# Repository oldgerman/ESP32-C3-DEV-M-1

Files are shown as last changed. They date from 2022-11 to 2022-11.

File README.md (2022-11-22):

## ESP32-C3-DevKitM-1

> 基于ESP32-C3的开发板，[ESP32-C3-DEVKITM-1](https://docs.espressif.com/projects/esp-idf/zh_CN/latest/esp32c3/hw-reference/esp32c3/user-guide-devkitm-1.html)的重制版，保持十分考究的布局，提供AD原始工程、Gerber、BOM

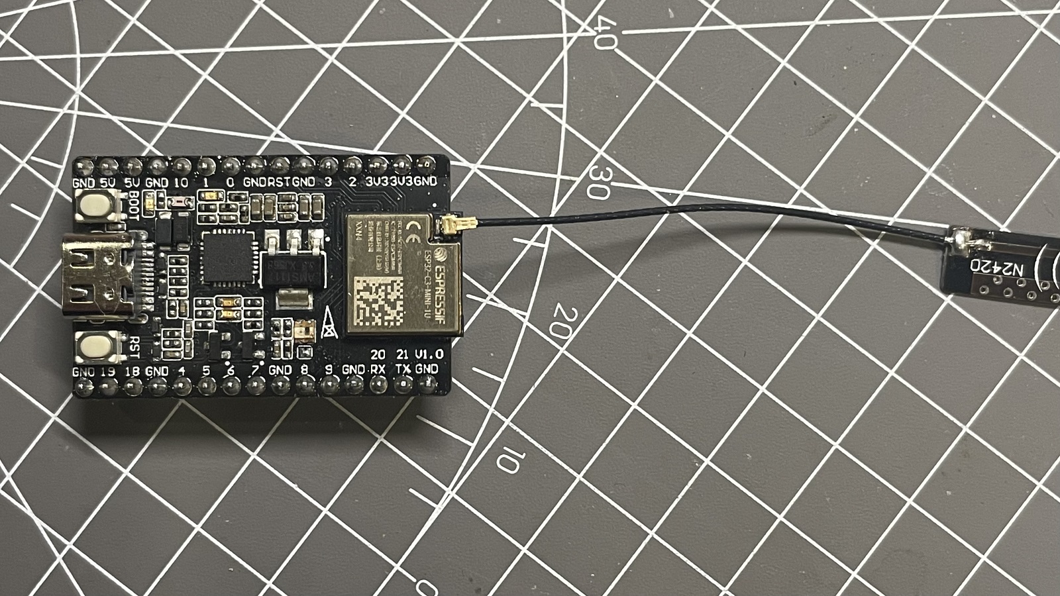
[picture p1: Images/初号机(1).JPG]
初号机(1)


[Github仓库链接](https://github.com/oldgerman/ESP32-C3-DEV-M-1)

## PCB

| 使用ESP32-C3 MINI-1模组 | 使用ESP32-C3 MINI-1U模组 |
| --- | --- |
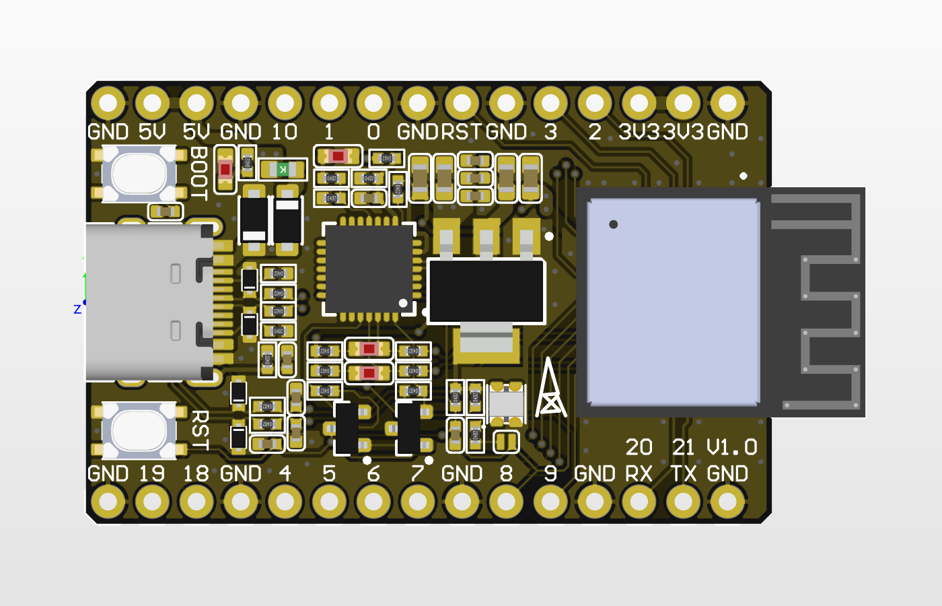
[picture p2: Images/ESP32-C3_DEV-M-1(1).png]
ESP32-C3_DEV-M-1(1)
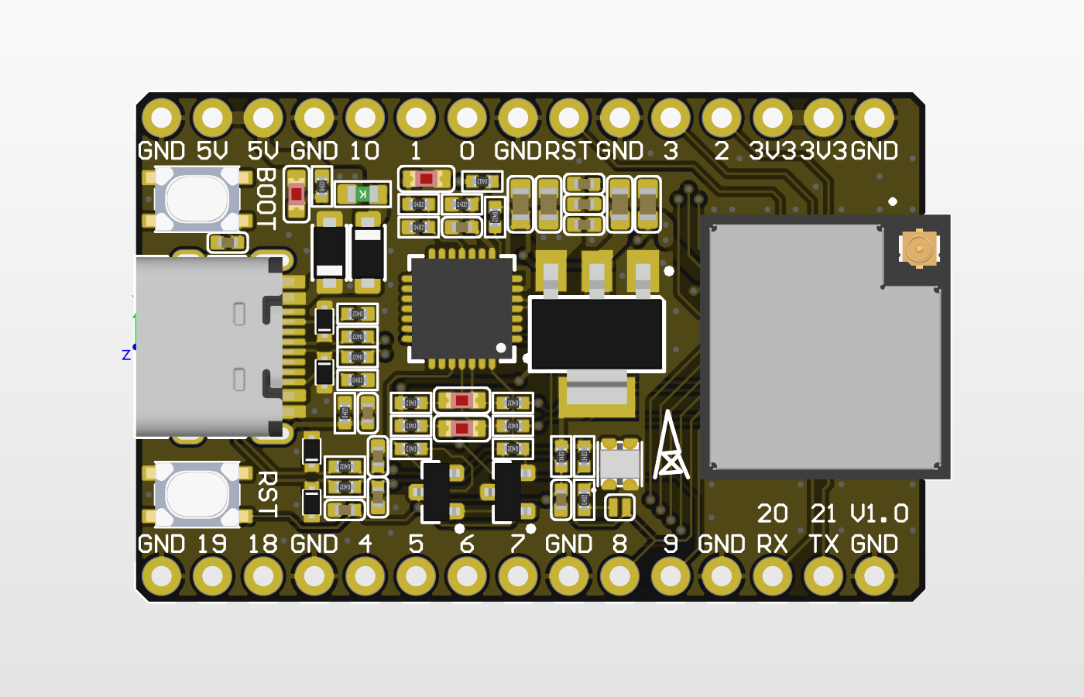
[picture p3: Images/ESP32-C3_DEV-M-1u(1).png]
ESP32-C3_DEV-M-1u(1)
|  |  |
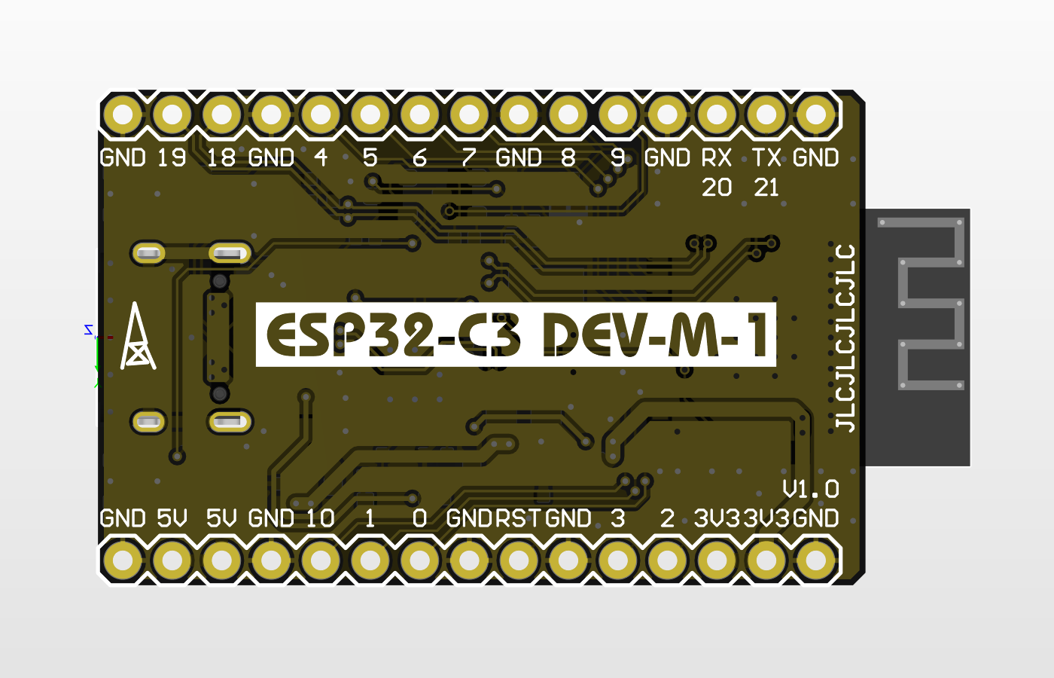
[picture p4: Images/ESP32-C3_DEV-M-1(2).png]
ESP32-C3_DEV-M-1(2)
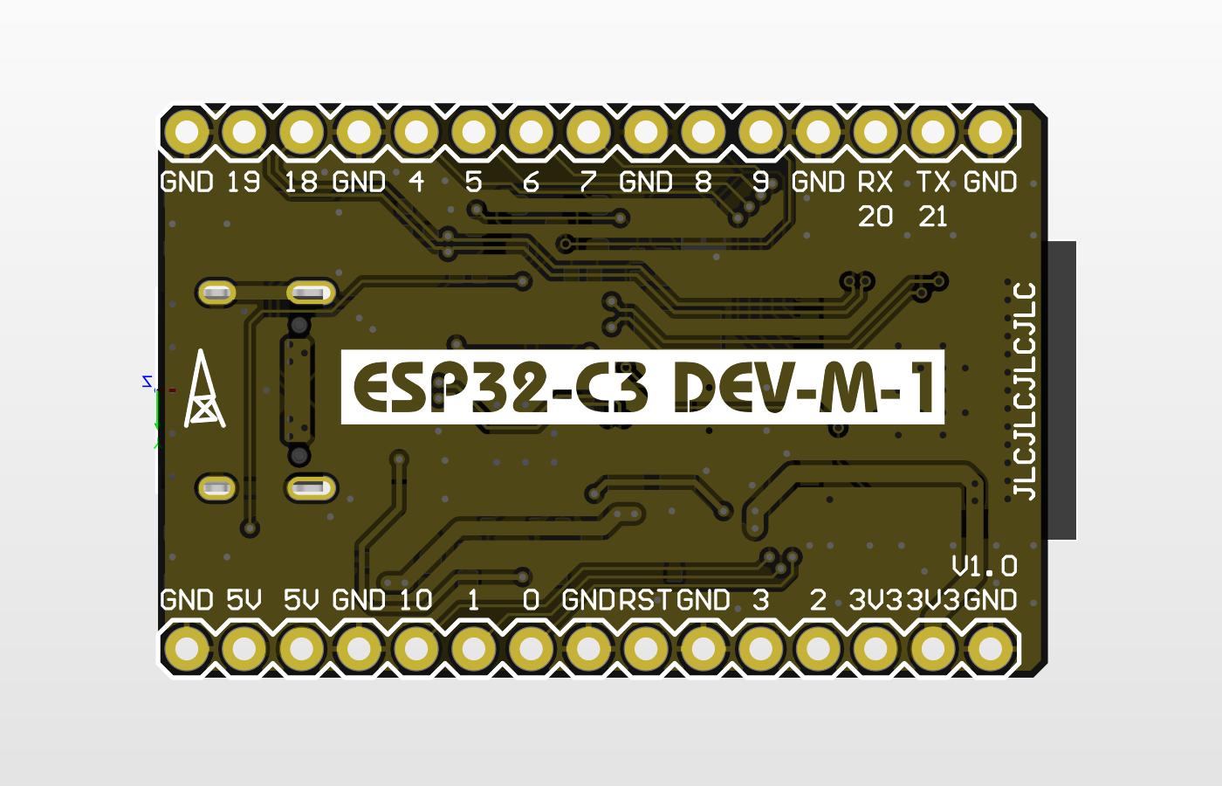
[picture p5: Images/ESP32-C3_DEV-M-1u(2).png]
ESP32-C3_DEV-M-1u(2)
|  |  |
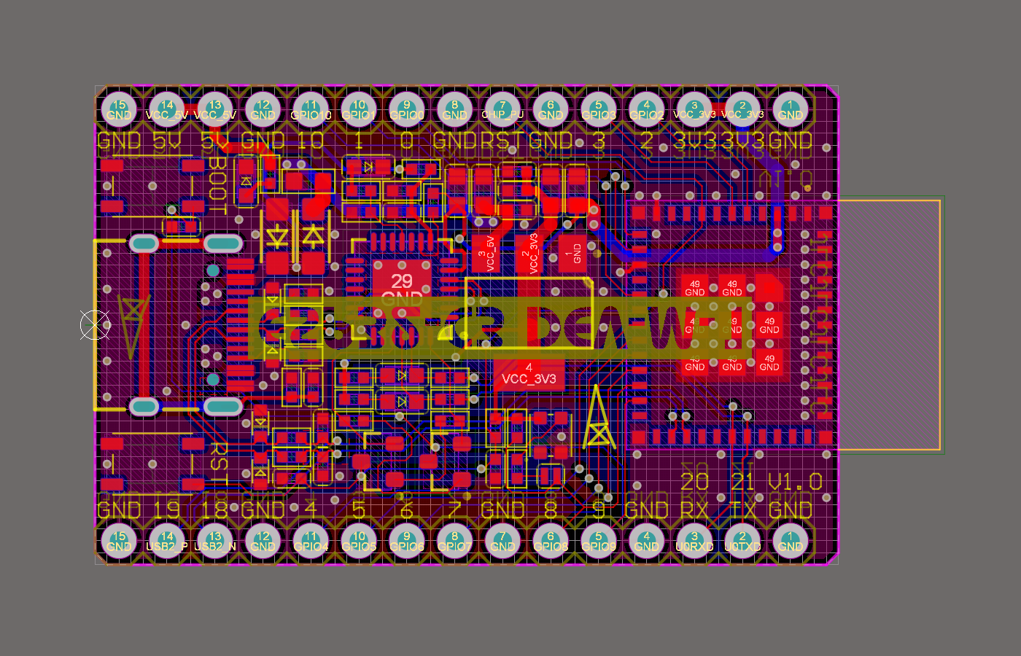
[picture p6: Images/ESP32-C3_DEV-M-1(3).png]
ESP32-C3_DEV-M-1(3)
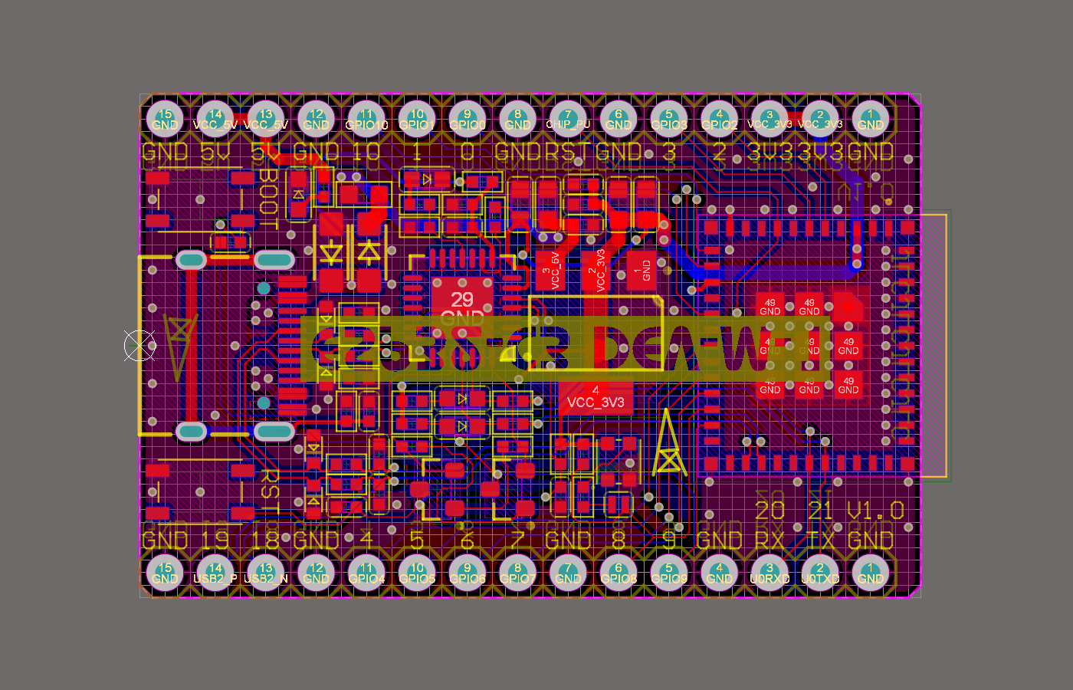
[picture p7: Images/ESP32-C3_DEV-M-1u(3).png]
ESP32-C3_DEV-M-1u(3)
|  |  |

## 工艺

- 板厚：1.0~1.6mm 均可
- 层数：2层
- 过孔：0.3/0.5mm
- 最小线宽线隙：5mil

## Type-C正反插

- 正插：使用CP2102的串口
- 反插：使用ESP32-C3FN4或ESP32-C3FH4片内集成的USB串口，可以不焊接CP2102相关的电路使用ESP32-C3自带的USB串口桥烧录或者调试

## 亮机测试

模组焊接很难，对锡膏均匀度要求很高，不开钢网很难搞

Example文件夹内有最基本的wifi、GPIO、串口、RGB灯测试

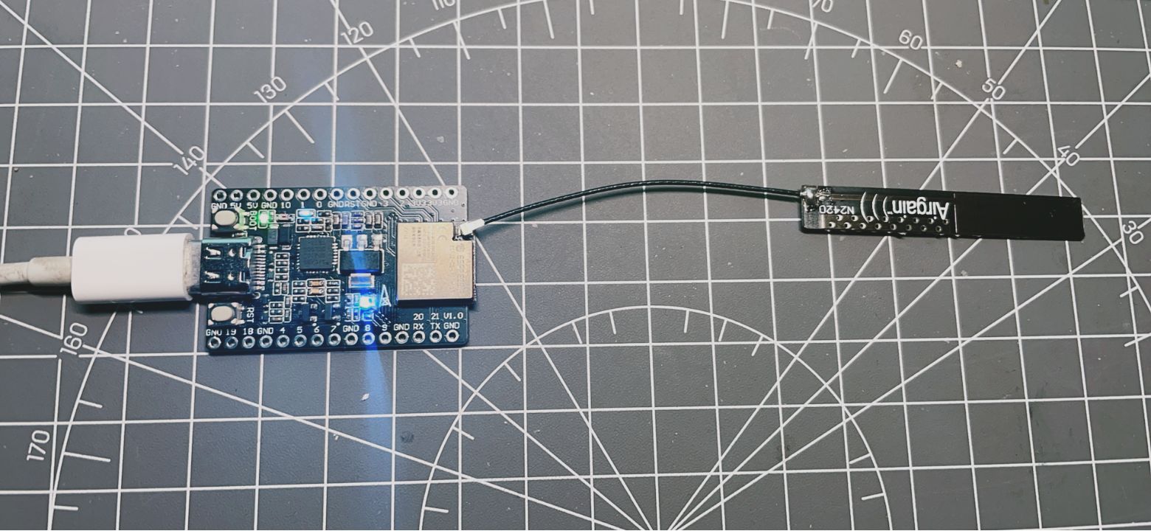
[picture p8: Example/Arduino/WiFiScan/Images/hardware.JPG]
hardware


## 烧录程序

乐鑫工具：[Flash Download Tools](https://www.espressif.com/en/support/download/other-tools)

Arduino环境：简单些，一键选择esp32-c3开发板，一键就行

ESP-IDF：待补充

## 按键boot和reset组合，尝试进入下载模式，但不打印 “waiting for download”，仍然一直打印invalid header: 0xffffffff？

使用全新的模组，首次焊接好通电，不论是esp32-c3自身串口，还是cp2102的串口，会一直打印invalid header: 0xffffffff，然后自己复位，如此反复，如果GPIO8是高电平，按键boot和reset组合进入下载模式却不打印 “waiting for download”，那么是正常现象，因为出厂是不带BOOT的，可以使用flash_download_tool连接开发板进入下载模式，只需要连接一次，烧录bootloader.bin在0x0地址，然后就可以按下boot键不放，按下松开一次reset键，进入下载模式就会打印 “waiting for download”，或者随便烧录一个arduino esp32-c3例程进去，也可以解决

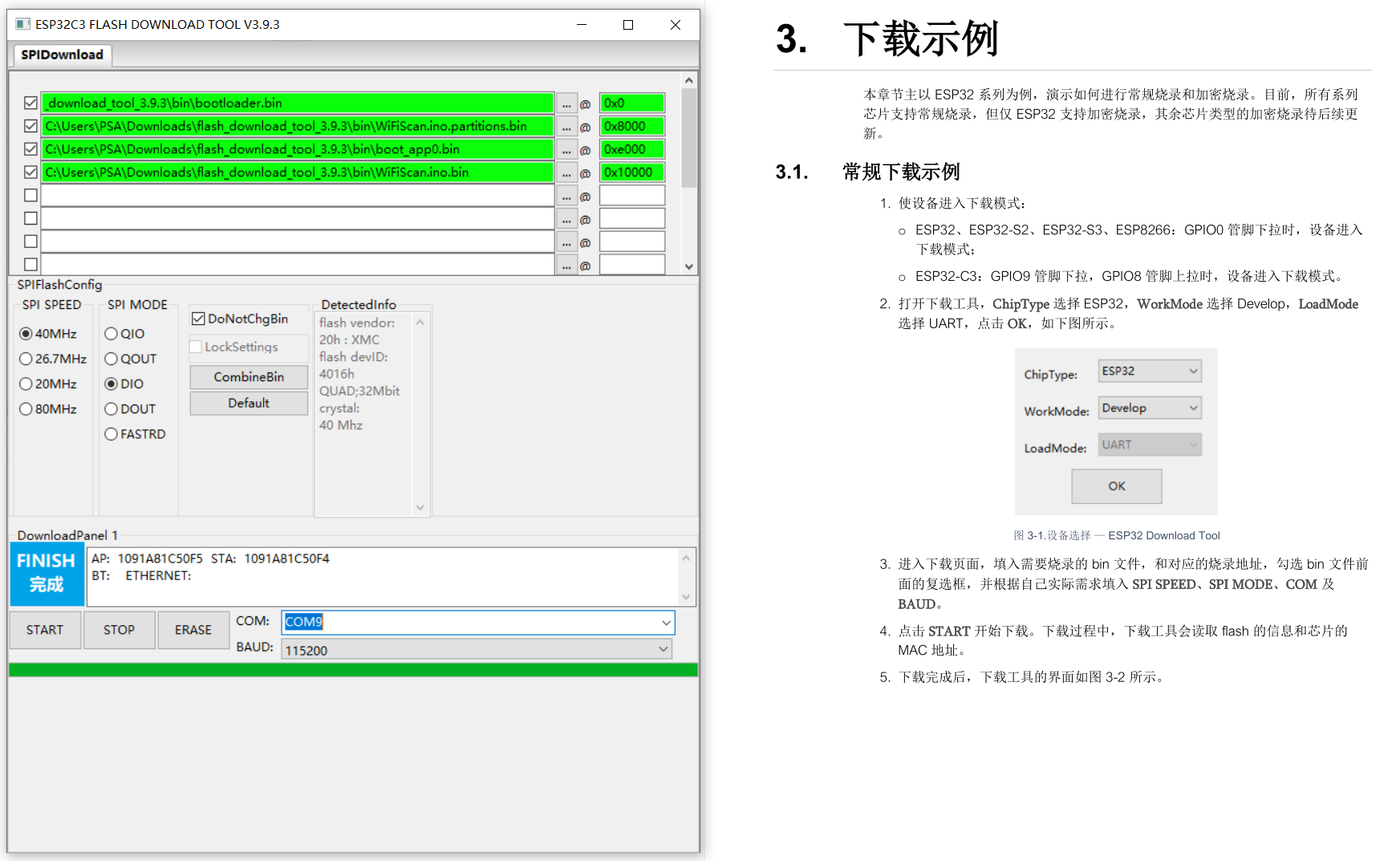
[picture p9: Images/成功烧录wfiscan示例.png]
成功烧录wfiscan示例


```
ESP-ROM:esp32c3-api1-20210207
Build:Feb  7 2021
rst:0x15 (USB_UART_CHIP_RESET),boot:0x4 (DOWNLOAD(USB/UART0/1))
Saved PC:0x400462e2
waiting for download   <----按键boot和reset组合，尝试进入下载模式OK，esp32-3本身片内的串口桥或者cp2102都可以
```

## 碎碎念

最近的准备用STM32测试[esp-hosted](https://github.com/espressif/esp-hosted)，ESP32-C3拥有[ESP-Hosted-FG]() SPI模式最高的吞吐量(TX/RX 17Mbps)，[ESP32-C3 MINI-1U]()模组又是这几款ESP32提供的模组中尺寸最小的，遂选型之，由于直接使用模组，那么就不用设计模组内的电路部分了，直接找乐鑫官网[ESP32-C3-DEVKITM-1](https://docs.espressif.com/projects/esp-idf/zh_CN/latest/esp32c3/hw-reference/esp32c3/user-guide-devkitm-1.html)开发板（都2202年了还是Micro-USB接口？）提供的原理图和PDF格式的PCB布局做参考，本以为[ESP32-C3-DEVKITM-1](https://docs.espressif.com/projects/esp-idf/zh_CN/latest/esp32c3/hw-reference/esp32c3/user-guide-devkitm-1.html)这块两层板挺好搞定，然而细看背面布局发现画板子的工程师追求连续的GND（UART总线或者USB差分对与其他信号线之间必有GND），给改Type-C增加了不少麻烦

## 参考资料

[ESP32-C3-DevKitM-1：快速入门](https://docs.espressif.com/projects/esp-idf/zh_CN/latest/esp32c3/hw-reference/esp32c3/user-guide-devkitm-1.html)

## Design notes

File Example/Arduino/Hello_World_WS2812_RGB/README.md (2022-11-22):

## 测试板子上的RGB灯

- WS2812按照色轮变化颜色
- 串口打印 hello World

<video src="Images/demo.MP4"></video>

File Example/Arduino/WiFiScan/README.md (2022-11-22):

## Wifi信号强度测试

- 测试：天线是否抽风

hardware

### Boot信息

```
ESP-ROM:esp32c3-api1-20210207
Build:Feb  7 2021
rst:0x1 (POWERON),boot:0xc (SPI_FAST_FLASH_BOOT)
SPIWP:0xee
mode:DIO, clock div:1
load:0x3fcd6100,len:0x420
load:0x403ce000,len:0x90c
load:0x403d0000,len:0x236c
SHA-256 comparison failed:
Calculated: ccb0d00bac7e84e1d90a12e4f75f4ab6c5f7e71bb209afd5819c4c9557a6db71
Expected: c9cf160580940ec7801c73b16423824e72ad12055c732e83ce66332240af42a7
Attempting to boot anyway...
entry 0x403ce000
Setup done
```

### 未安装天线前

```
scan start
scan done
2 networks found
1: PDCN (-59)*
2: PDCN (-91)*

scan start
scan done
2 networks found
1: PDCN (-67)*
2: PDCN (-90)*

scan start
scan done
2 networks found
1: PDCN (-58)*
2: PDCN (-87)*

scan start
scan done
1 networks found
1: PDCN (-63)*

scan start
scan done
2 networks found
1: PDCN (-58)*
2: PDCN (-92)*

```

### 安装4dBi 天线

####   距离路由器天线60cm

```
scan start
scan done
5 networks found
1: PDCN (-7)*
2: PDCN (-38)*
3: ROOM (-72)*
4: @PHICOMM_54 (-75)*
5: suibianwo (-80)*

scan start
scan done
4 networks found
1: PDCN (-12)*
2: PDCN (-38)*
3: @PHICOMM_54 (-73)*
4: ROOM (-73)*
```

#### 距离路由器天线5cm

```

scan start
scan done
7 networks found
1: PDCN (-26)*
2: PDCN (-55)*
3: D5-4-2 (-75)*
4: TP-LINK_C341 (-86)*
5: zhang (-87)*
6: Wireless Router (-89) 
7: suibianwo (-89)*

scan start
scan done
8 networks found
1: PDCN (-30)*
2: PDCN (-56)*
3: D5-4-2 (-87)*
4: @PHICOMM_54 (-88)*
5: D-6-1 (-88)*
6: suibianwo (-89)*
7: lyf (-89)*
8: 360WiFi-2FF6B6 (-90)*

```

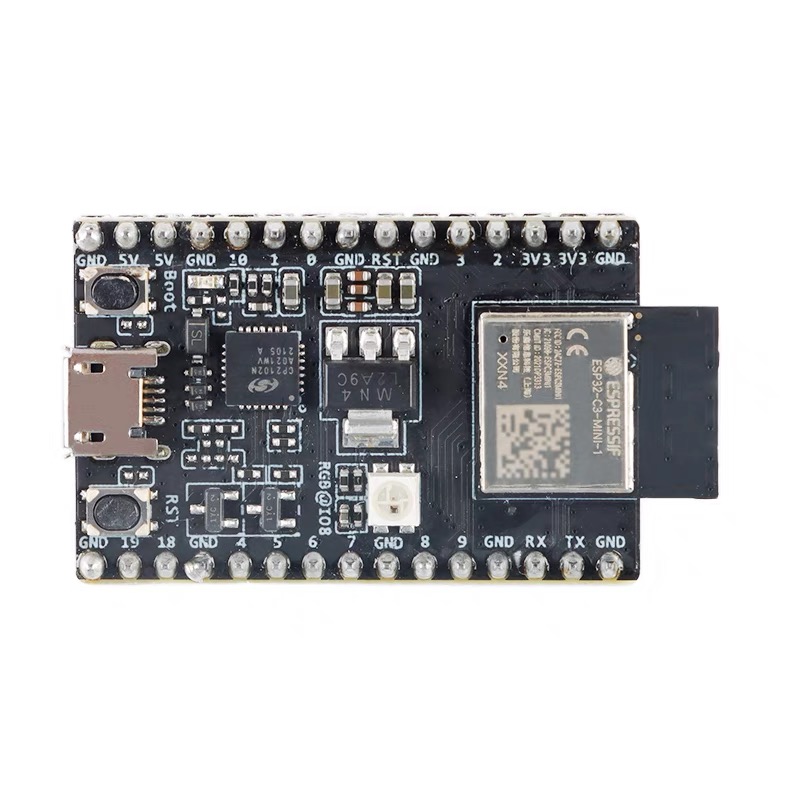
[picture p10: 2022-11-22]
Reference/ESP32-C3-DEVKITM-1/Images/ESP32-C3-DEVKITM-1_Brd(2).JPG

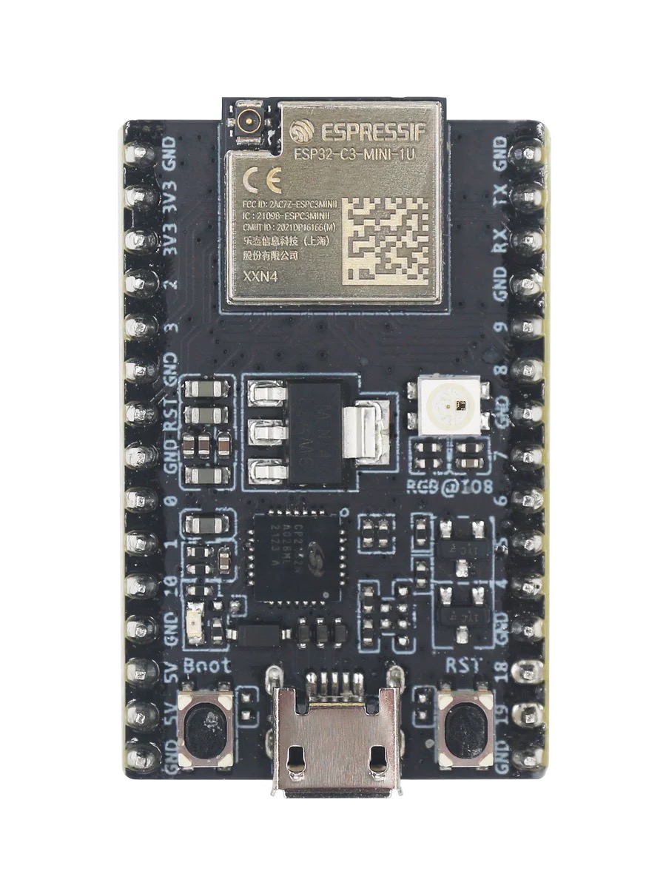
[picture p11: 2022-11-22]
Reference/ESP32-C3-DEVKITM-1/Images/ESP32-C3-DEVKITM-1_Brd(1).JPG

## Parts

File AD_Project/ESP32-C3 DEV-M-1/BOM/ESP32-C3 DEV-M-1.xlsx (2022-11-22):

Comment | Designator | Footprint
4.7nF | C1 | C0402
10uF/10V(10%) | C2, C7, C10, C11 | C0603
1uF/16V(10%) | C3, C4, C14 | C0402
22pF/50V(5%) | C5, C6 | C0402
0.1uF/50V(10%) | C8, C9, C12, C13 | C0402
DSK16 | D1 | SOD123F
SMF5.0A | D2 | SOD123F
ESD5B5.05T1G | D3, D4, D5, D6 | SOD-523
6V/0.5A/1A | F1 | FUSE0603_0.5MM
LED | LED1, LED2, LED3, LED4 | LED0603_RED
ODG_LOGO | ODG1, ODG2 | ODG_LOGO
CONN_X15 | P1, P2 | 2.54MM_MALE_X15
S8050 | Q1, Q2 | INFINEON SOT-23-3
5.1K(1%) | R1, R2, R12, R21, R22 | R0402
1M | R3 | R0402
47K(1%) | R16 | R0402
22R(1%) | R5, R6, R7, R8, R10, R11 | R0402
10K(1%) | R4, R9 | R0402
10K(1%)(NC) | R13 | R0402
22K(1%) | R14 | R0402
1K(1%) | R15 | R0402
0R(1%) | R17 | R0402
3.3K(1%) | R18, R19, R20 | R0402
SJ_2P | SJ1 | SJ_2P_MINI
Button-4P | SW1, SW2 | SWITCH_3X4X2.5_4PIN_SMD
ESP32-C3-MINI-1U-N4 (A) | U1 | XCVR_ESP32-C3-MINI-1U-N4
AMS1117-3.3 | U2 | TI SOT-223 DCY
CP2102-GMR | U3 | QFN-28_EP
WS2812 | U4 | WS2812_2020
Type-C | USB1 | Type-C-TOP

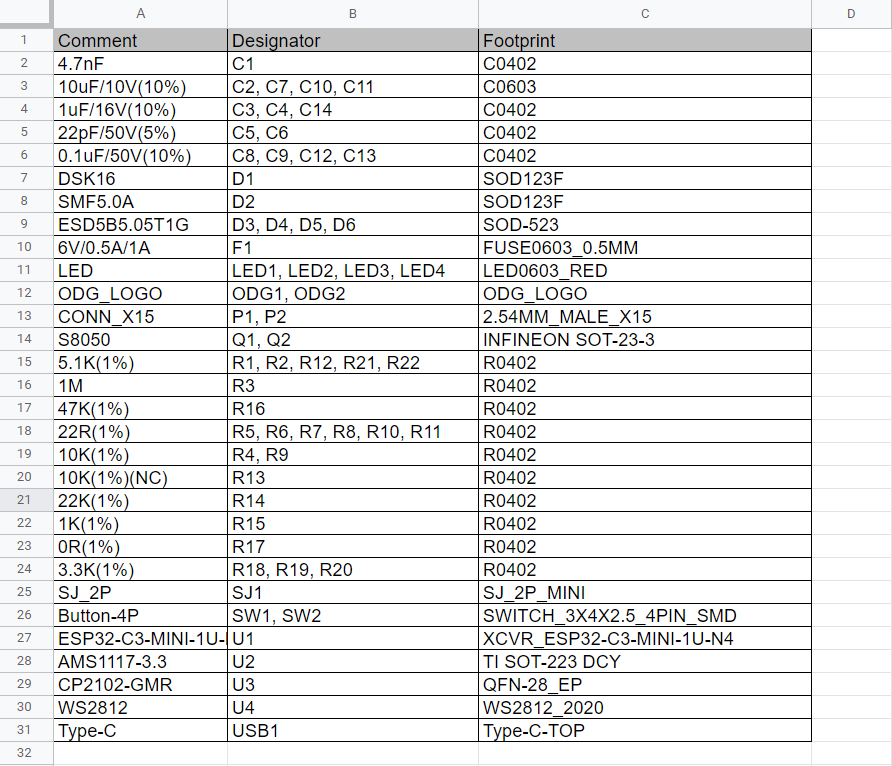
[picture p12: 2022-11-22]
AD_Project/ESP32-C3 DEV-M-1/BOM/BOM.png

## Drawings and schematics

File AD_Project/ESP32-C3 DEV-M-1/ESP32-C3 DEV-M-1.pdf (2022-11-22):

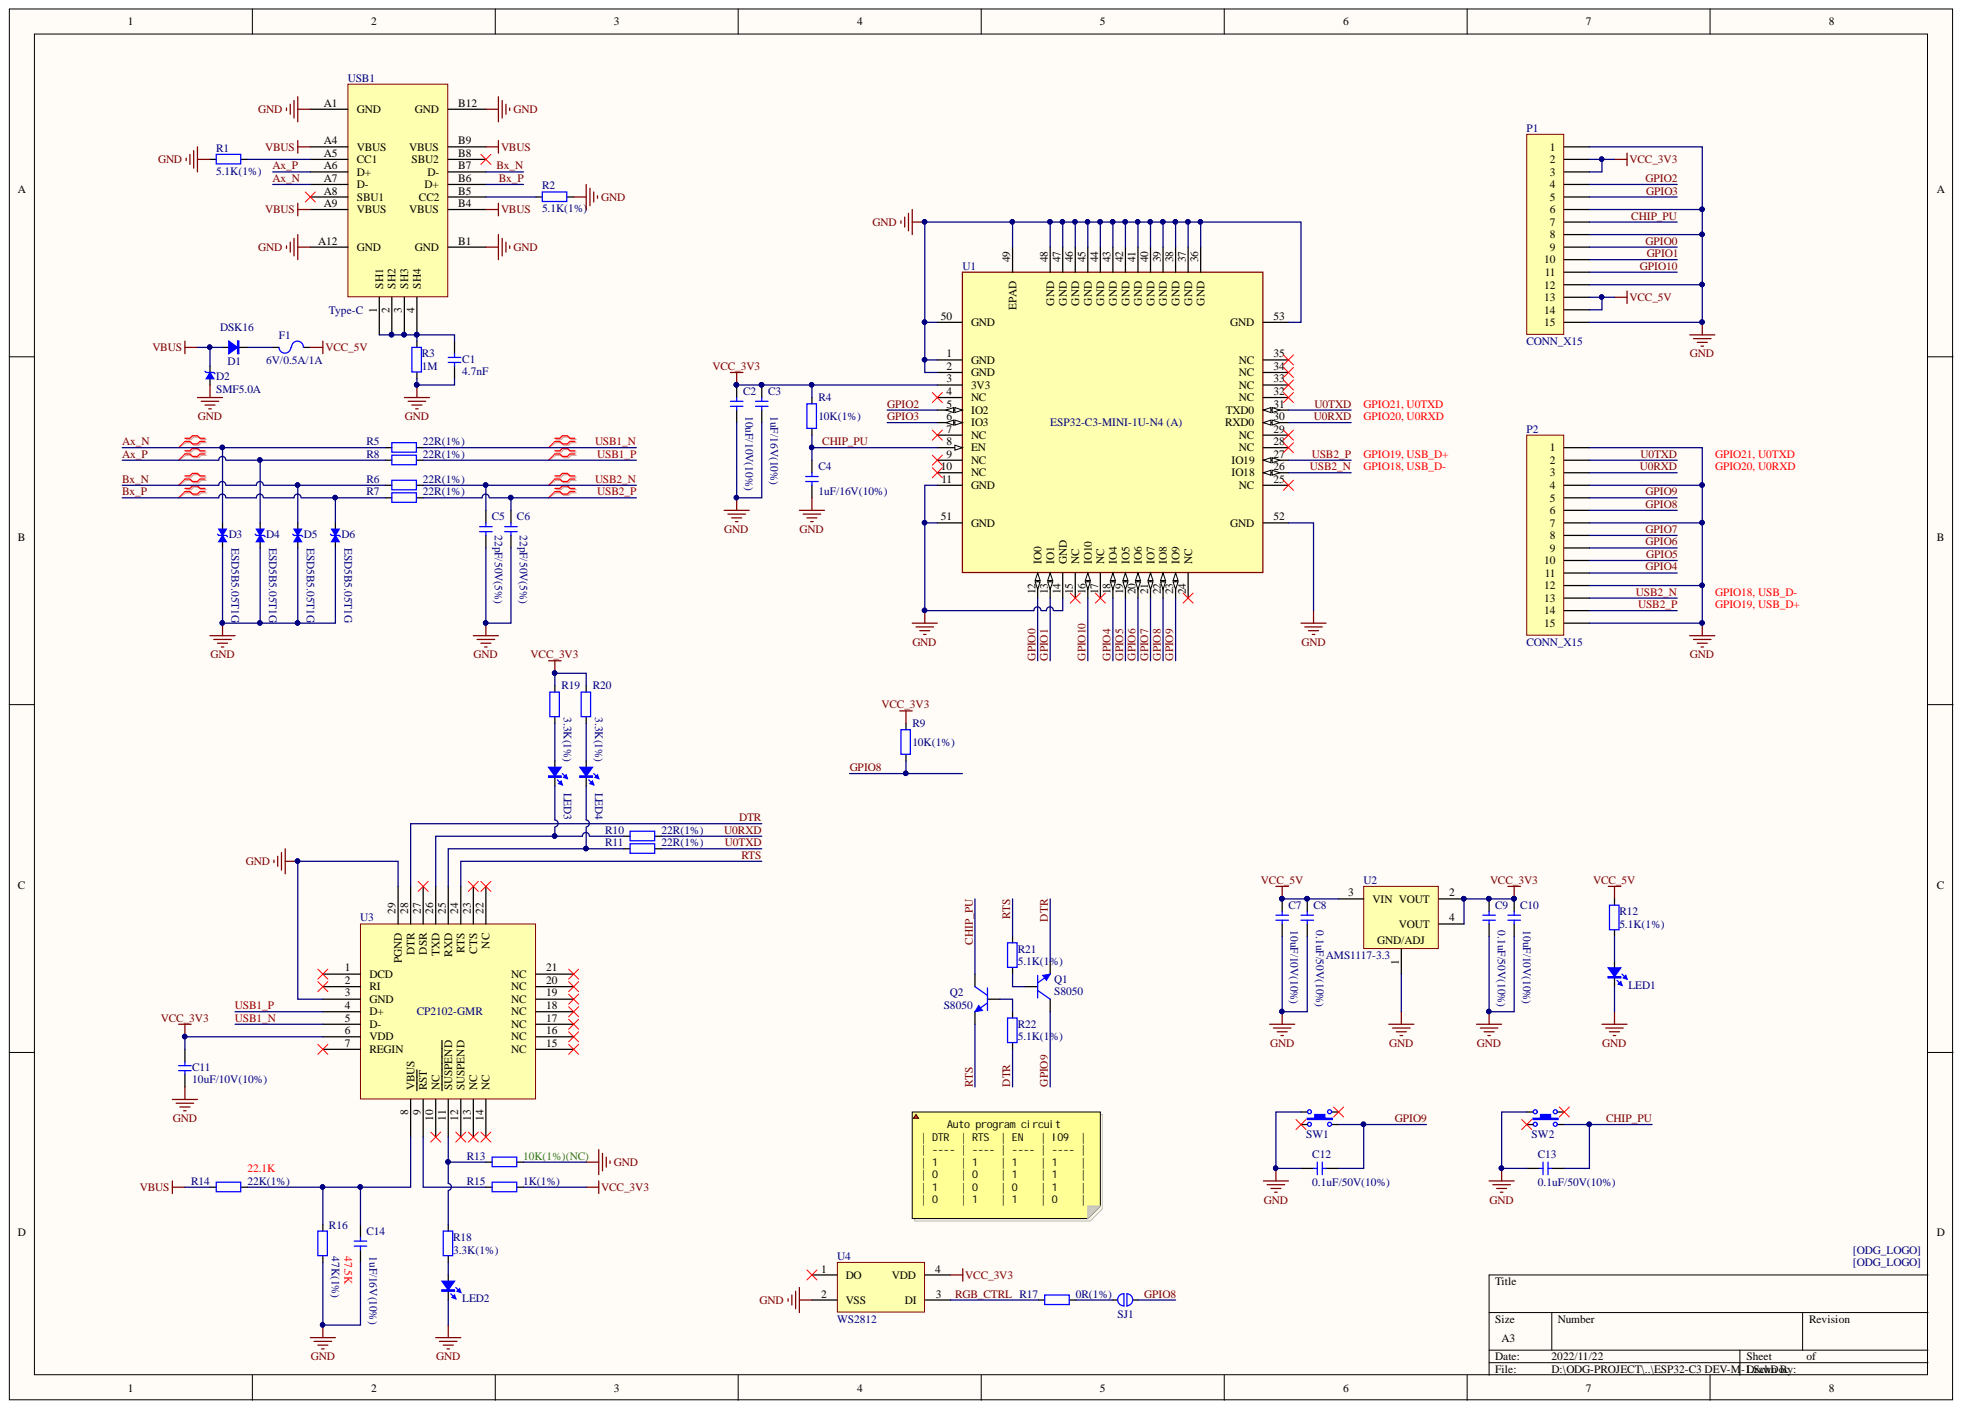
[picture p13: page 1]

GND 36 GND 37 GND 38 GND 39 GND 40 GND 41 GND 42 GND 43 GND 44 GND 45 GND 46 GND 47 GND 48

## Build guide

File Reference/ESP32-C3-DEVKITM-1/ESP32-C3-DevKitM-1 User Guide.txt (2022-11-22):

https://docs.espressif.com/projects/esp-idf/zh_CN/latest/esp32c3/hw-reference/esp32c3/user-guide-devkitm-1.html
https://docs.espressif.com/projects/esp-idf/zh_CN/latest/esp32c3/hw-reference/esp32c3/user-guide-devkitm-1.html
https://docs.espressif.com/projects/esp-idf/zh_CN/latest/esp32c3/hw-reference/esp32c3/user-guide-devkitm-1.html

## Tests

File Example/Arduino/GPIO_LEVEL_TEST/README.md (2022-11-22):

## 简单粗暴的GPIO电平翻转测试

- 测试对象：GPIO0-->10，GPIO18-->21，即开发板15个引出到2.54杜邦接口的GPIO
- 例程：5Hz方波，奇数与偶数GPIO电平互为相反，因为模组的GPIO是奇偶奇偶排列的，所以可以检查焊接问题，虚焊&连锡

## demo

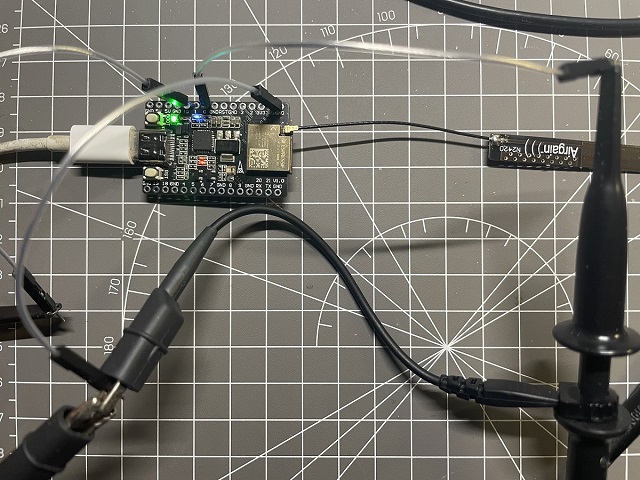
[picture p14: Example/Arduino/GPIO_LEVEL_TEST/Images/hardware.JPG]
hardware
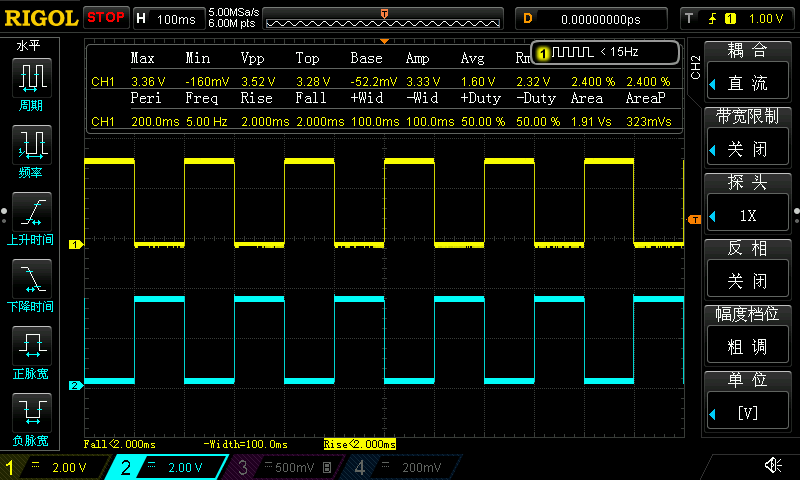
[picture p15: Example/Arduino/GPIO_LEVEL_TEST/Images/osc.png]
osc
|  |  |
| --- | --- |

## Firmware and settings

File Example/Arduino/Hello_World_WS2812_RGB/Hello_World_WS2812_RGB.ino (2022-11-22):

/*
  Blink

  Turns an LED on for one second, then off for one second, repeatedly.

  Most Arduinos have an on-board LED you can control. On the UNO, MEGA and ZERO
  it is attached to digital pin 13, on MKR1000 on pin 6. LED_BUILTIN is set to
  the correct LED pin independent of which board is used.
  If you want to know what pin the on-board LED is connected to on your Arduino
  model, check the Technical Specs of your board at:
  https://www.arduino.cc/en/Main/Products

  modified 8 May 2014
  by Scott Fitzgerald
  modified 2 Sep 2016
  by Arturo Guadalupi
  modified 8 Sep 2016
  by Colby Newman

  This example code is in the public domain.

  http://www.arduino.cc/en/Tutorial/Blink
*/


#include <Adafruit_NeoPixel.h>


// Which pin on the Arduino is connected to the NeoPixels?
// On a Trinket or Gemma we suggest changing this to 1:
#define LED_PIN     8 //ESP32-C3 GPIO8

// How many internal neopixels do we have? some boards have more than one!
#define NUMPIXELS        1

// NeoPixel brightness, 0 (min) to 255 (max)
#define BRIGHTNESS 50 // Set BRIGHTNESS to about 1/5 (max = 255)

Adafruit_NeoPixel strip(NUMPIXELS, LED_PIN, NEO_GRB + NEO_KHZ800);

// Argument 1 = Number of pixels in NeoPixel strip
// Argument 2 = Arduino pin number (most are valid)
// Argument 3 = Pixel type flags, add together as needed:
//   NEO_KHZ800  800 KHz bitstream (most NeoPixel products w/WS2812 LEDs)
//   NEO_KHZ400  400 KHz (classic 'v1' (not v2) FLORA pixels, WS2811 drivers)
//   NEO_GRB     Pixels are wired for GRB bitstream (most NeoPixel products)
//   NEO_RGB     Pixels are wired for RGB bitstream (v1 FLORA pixels, not v2)
//   NEO_RGBW    Pixels are wired for RGBW bitstream (NeoPixel RGBW products)



// the setup function runs once when you press reset or power the board
void setup() {
  Serial.begin(115200);

  strip.begin();           // INITIALIZE NeoPixel strip object (REQUIRED)
  strip.show();            // Turn OFF all pixels ASAP
  strip.setBrightness(BRIGHTNESS);
  
}


// loop() function -- runs repeatedly as long as board is on ---------------

void loop() {
  
  Serial.println("Hello World!");
  // Fill along the length of the strip in various colors...
//  colorWipe(strip.Color(255,   0,   0), 50); // Red
//  colorWipe(strip.Color(  0, 255,   0), 50); // Green
//  colorWipe(strip.Color(  0,   0, 255), 50); // Blue
//
//  // Do a theater marquee effect in various colors...
//  theaterChase(strip.Color(127, 127, 127), 50); // White, half brightness
//  theaterChase(strip.Color(127,   0,   0), 50); // Red, half brightness
//  theaterChase(strip.Color(  0,   0, 127), 50); // Blue, half brightness

  rainbow(10);             // Flowing rainbow cycle along the whole strip
//  theaterChaseRainbow(50); // Rainbow-enhanced theaterChase variant
}


// Some functions of our own for creating animated effects -----------------

// Fill strip pixels one after another with a color. Strip is NOT cleared
// first; anything there will be covered pixel by pixel. Pass in color
// (as a single 'packed' 32-bit value, which you can get by calling
// strip.Color(red, green, blue) as shown in the loop() function above),
// and a delay time (in milliseconds) between pixels.
void colorWipe(uint32_t color, int wait) {
  for(int i=0; i<strip.numPixels(); i++) { // For each pixel in strip...
    strip.setPixelColor(i, color);         //  Set pixel's color (in RAM)
    strip.show();                          //  Update strip to match
    delay(wait);                           //  Pause for a moment
  }
}

// Theater-marquee-style chasing lights. Pass in a color (32-bit value,
// a la strip.Color(r,g,b) as mentioned above), and a delay time (in ms)
// between frames.
void theaterChase(uint32_t color, int wait) {
  for(int a=0; a<10; a++) {  // Repeat 10 times...
    for(int b=0; b<3; b++) { //  'b' counts from 0 to 2...
      strip.clear();         //   Set all pixels in RAM to 0 (off)
      // 'c' counts up from 'b' to end of strip in steps of 3...
      for(int c=b; c<strip.numPixels(); c += 3) {
        strip.setPixelColor(c, color); // Set pixel 'c' to value 'color'
      }
      strip.show(); // Update strip with new contents
      delay(wait);  // Pause for a moment
    }
  }
}

// Rainbow cycle along whole strip. Pass delay time (in ms) between frames.
void rainbow(int wait) {
  // Hue of first pixel runs 5 complete loops through the color wheel.
  // Color wheel has a range of 65536 but it's OK if we roll over, so
  // just count from 0 to 5*65536. Adding 256 to firstPixelHue each time
  // means we'll make 5*65536/256 = 1280 passes through this loop:
  for(long firstPixelHue = 0; firstPixelHue < 5*65536; firstPixelHue += 256) {
    // strip.rainbow() can take a single argument (first pixel hue) or
    // optionally a few extras: number of rainbow repetitions (default 1),
    // saturation and value (brightness) (both 0-255, similar to the
    // ColorHSV() function, default 255), and a true/false flag for whether
    // to apply gamma correction to provide 'truer' colors (default true).
    strip.rainbow(firstPixelHue);
    // Above line is equivalent to:
    // strip.rainbow(firstPixelHue, 1, 255, 255, true);
    strip.show(); // Update strip with new contents
    delay(wait);  // Pause for a moment
    Serial.println("Hello World!");
  }
}

// Rainbow-enhanced theater marquee. Pass delay time (in ms) between frames.
void theaterChaseRainbow(int wait) {
  int firstPixelHue = 0;     // First pixel starts at red (hue 0)
  for(int a=0; a<30; a++) {  // Repeat 30 times...
    for(int b=0; b<3; b++) { //  'b' counts from 0 to 2...
      strip.clear();         //   Set all pixels in RAM to 0 (off)
      // 'c' counts up from 'b' to end of strip in increments of 3...
      for(int c=b; c<strip.numPixels(); c += 3) {
        // hue of pixel 'c' is offset by an amount to make one full
        // revolution of the color wheel (range 65536) along the length
        // of the strip (strip.numPixels() steps):
        int      hue   = firstPixelHue + c * 65536L / strip.numPixels();
        uint32_t color = strip.gamma32(strip.ColorHSV(hue)); // hue -> RGB
        strip.setPixelColor(c, color); // Set pixel 'c' to value 'color'
      }
      strip.show();                // Update strip with new contents
      delay(wait);                 // Pause for a moment
      firstPixelHue += 65536 / 90; // One cycle of color wheel over 90 frames
    }
  }
}

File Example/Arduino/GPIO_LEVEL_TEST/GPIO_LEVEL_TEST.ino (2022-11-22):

void setup() {
  // put your setup code here, to run once:
  pinMode(0, OUTPUT);
  pinMode(1, OUTPUT);
  pinMode(2, OUTPUT);
  pinMode(3, OUTPUT);
  pinMode(4, OUTPUT);
  pinMode(5, OUTPUT);
  pinMode(6, OUTPUT);
  pinMode(7, OUTPUT);
  pinMode(8, OUTPUT);
  pinMode(9, OUTPUT);
  pinMode(10, OUTPUT);
  
  pinMode(18, OUTPUT);
  pinMode(19, OUTPUT);
  pinMode(20, OUTPUT);
  pinMode(21, OUTPUT);
}

void loop() {
  // put your main code here, to run repeatedly:
   digitalWrite(0, HIGH);   // turn the LED on (HIGH is the voltage level)
   digitalWrite(2, HIGH);   // turn the LED on (HIGH is the voltage level)
   digitalWrite(4, HIGH);   // turn the LED on (HIGH is the voltage level)
   digitalWrite(6, HIGH);   // turn the LED on (HIGH is the voltage level)
   digitalWrite(8, HIGH);   // turn the LED on (HIGH is the voltage level)
   digitalWrite(10, HIGH);   // turn the LED on (HIGH is the voltage level)
   digitalWrite(18, HIGH);   // turn the LED on (HIGH is the voltage level)
   digitalWrite(20, HIGH);   // turn the LED on (HIGH is the voltage level)
   
   digitalWrite(1, LOW);    // turn the LED off by making the voltage LOW
   digitalWrite(3, LOW);    // turn the LED off by making the voltage LOW
   digitalWrite(5, LOW);    // turn the LED off by making the voltage LOW
   digitalWrite(7, LOW);    // turn the LED off by making the voltage LOW
   digitalWrite(9, LOW);    // turn the LED off by making the voltage LOW
   digitalWrite(19, LOW);    // turn the LED off by making the voltage LOW
   digitalWrite(21, LOW);    // turn the LED off by making the voltage LOW
   delay(100); 


   digitalWrite(1, HIGH);   // turn the LED on (HIGH is the voltage level)
   digitalWrite(3, HIGH);   // turn the LED on (HIGH is the voltage level)
   digitalWrite(5, HIGH);   // turn the LED on (HIGH is the voltage level)
   digitalWrite(7, HIGH);   // turn the LED on (HIGH is the voltage level)
   digitalWrite(9, HIGH);   // turn the LED on (HIGH is the voltage level)
   digitalWrite(19, HIGH);    // turn the LED off by making the voltage LOW
   digitalWrite(21, HIGH);    // turn the LED off by making the voltage LOW
   
   digitalWrite(0, LOW);    // turn the LED off by making the voltage LOW
   digitalWrite(2, LOW);    // turn the LED off by making the voltage LOW
   digitalWrite(4, LOW);    // turn the LED off by making the voltage LOW
   digitalWrite(6, LOW);    // turn the LED off by making the voltage LOW
   digitalWrite(8, LOW);    // turn the LED off by making the voltage LOW
   digitalWrite(10, LOW);    // turn the LED off by making the voltage LOW
   digitalWrite(18, LOW);   // turn the LED on (HIGH is the voltage level)
   digitalWrite(20, LOW);   // turn the LED on (HIGH is the voltage level)
   delay(100);  
}

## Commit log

2022-11-22 添加焊接成品和测试例程
    [ESP32-C3 DEV-M-1.PcbDoc, ESP32-C3 DEV-M-1.PrjPcb, ESP32-C3 DEV-M-1.SchDoc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]
2022-11-22 修改readme
2022-11-22 添加Gerber
    [ESP32-C3 DEV-M-1.GBL, ESP32-C3 DEV-M-1.GBO, ESP32-C3 DEV-M-1.GBS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]
2022-11-22 添加排针
    [ESP32-C3 DEV-M-1.PcbDoc]
